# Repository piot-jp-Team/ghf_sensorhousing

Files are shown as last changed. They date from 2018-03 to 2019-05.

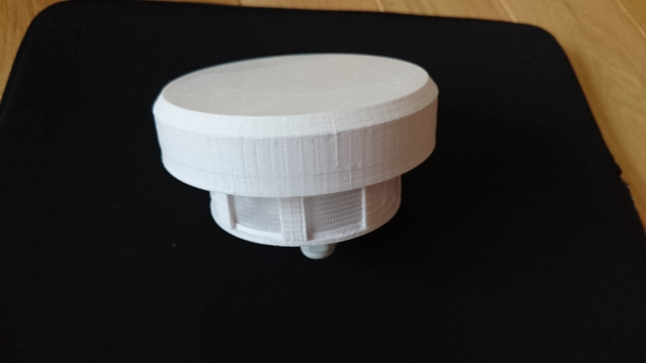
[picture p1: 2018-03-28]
DSC_0031.jpg

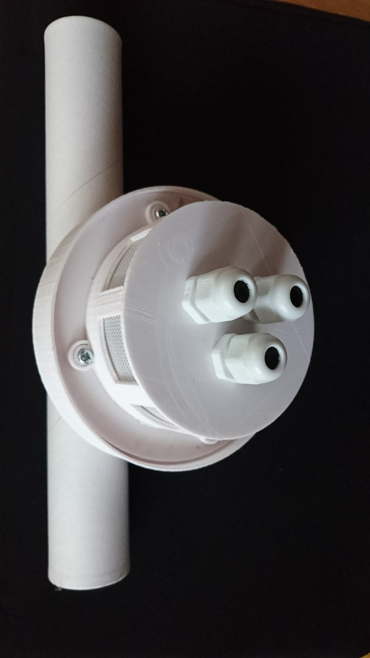
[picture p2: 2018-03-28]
DSC_0030.jpg

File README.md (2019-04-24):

# ghf_sensorhousing
## 農園センサーユニットハウジング
- arduino pro mini
- MH-Z19B 二酸化炭素センサ または　S-300G 二酸化炭素センサ
- AM2320 温湿度センサー
- リニア照度センサ
- 土壌水分センサ

## 仕組み
iot通信モジュールへRS485で取得データを送ります。  
sakura.io + arduino UNO  
sakura.ioから、laravel製のグラフで表示します。  
https://github.com/piot-jp-Team/ghf_webapp （日々更新中）  
シーケンス シーケンス図  

sakura.ioとの接続（Web Socket部分）は、https://github.com/piot-jp-Team/ghf_sakuraIO_wss_client  
今後はsigfox,lorawanも利用したいと思います。

## 使用するライブラリ   
(サーバ側)
- nginx, php7
- websocket クライアント　ratchetphp/Pawl
- phpフレームワーク laravel 5.6
- LaravelCharts
- mysql 5.7

(組み込み側)
- Arduino
- modbus/master slave
- S-300G or mhz19_uart
- Adafruit_Sensor
- Adafruit_AM2320
- sakura.io

## 開発ツール
- 筐体設計 OpenSCAD, FreeCAD
- PCB設計 Eagle6.6
- ファームウエア arduino IDE1.8.5
- エディタはATOM, PlantUML, Netbeans etc.

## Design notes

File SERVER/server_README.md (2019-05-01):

## サーバー側のソースコードは下記リポジトリです。  
Webアプリ  
https://github.com/piot-jp-Team/ghf_webapp 
  
sakura.io websocket　データ取得スクリプト  
https://github.com/piot-jp-Team/ghf_sakuraIO_wss_client

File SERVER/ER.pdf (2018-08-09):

エンティティ定義書 | 2018/8/9

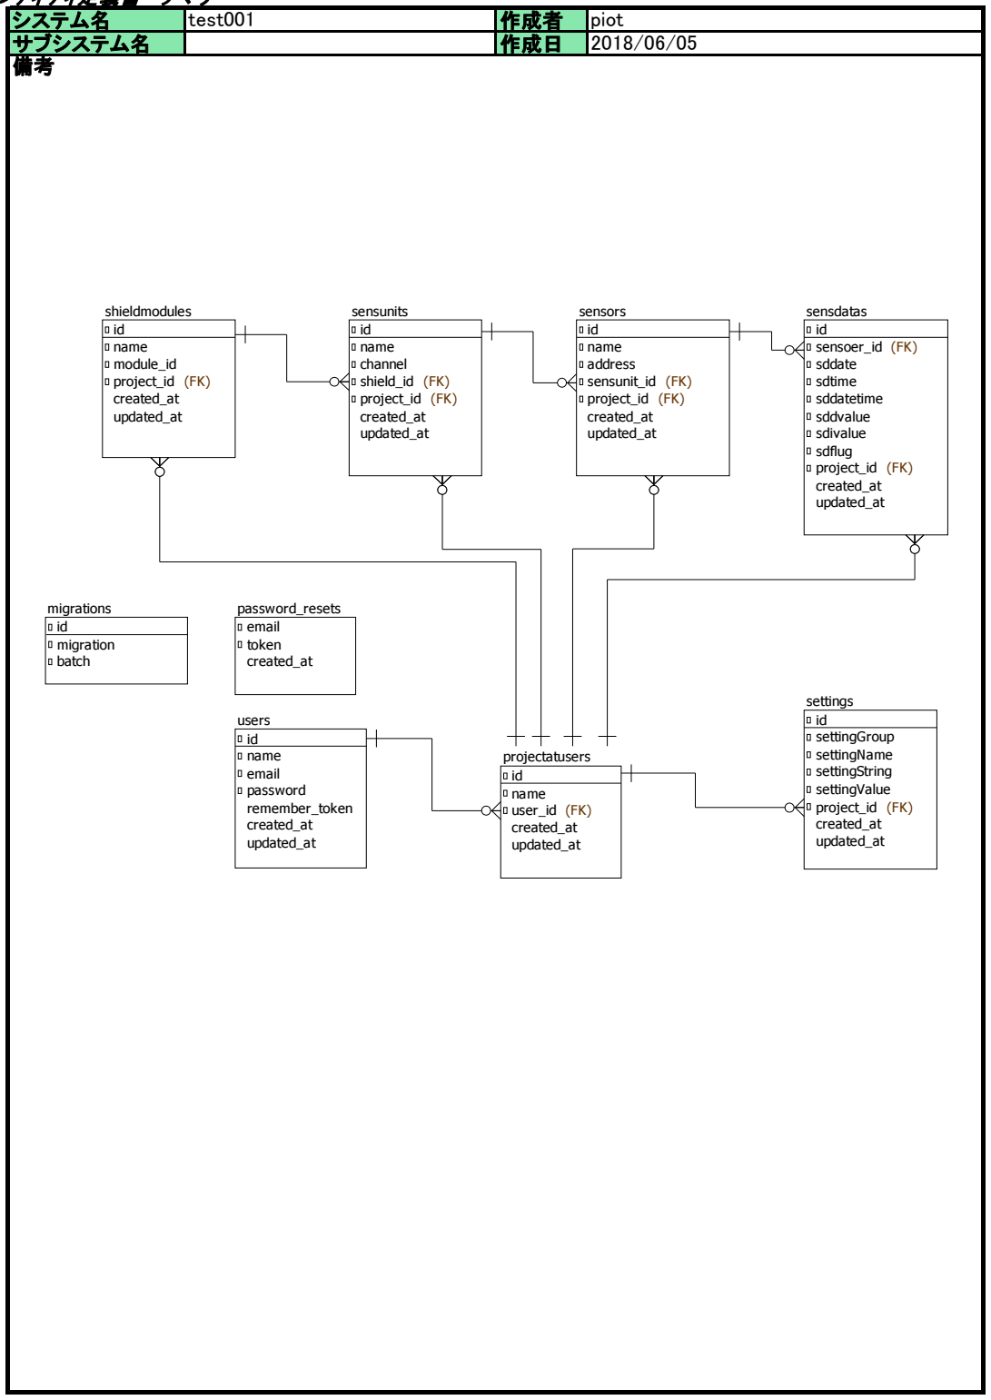
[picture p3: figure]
システム名; test001; 作成者; piot; サブシステム名; 作成日; migrations id migration batch; password_resets email token created_at; sensdatas id sensoer_id (FK) sddate sdtime sddatetime sddvalue sdivalue sdflug project_id (FK) created_at updated_at; sensors id name address sensunit_id (FK) project_id (FK) created_at updated_at; sensunits id name channel shield_id (FK) project_id (FK) created_at updated_at; settings id settingGroup settingName settingString settingValue project_id (FK) created_at updated_at; shieldmodules id name module_id project_id (FK) created_at updated_at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

## エンティティ定義書 サマリ

1/1

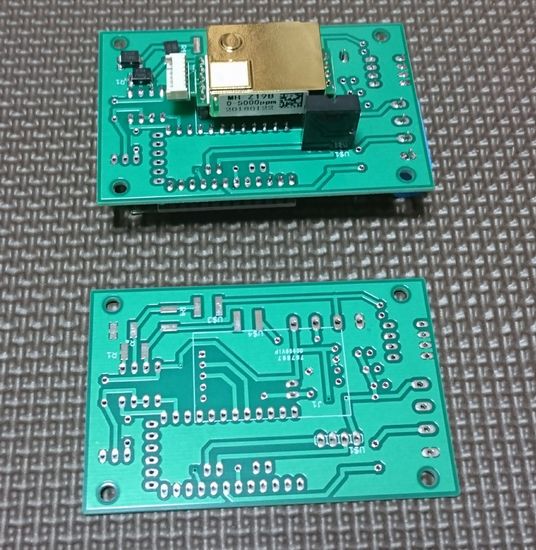
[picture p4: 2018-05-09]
PCB_bottomside.jpg

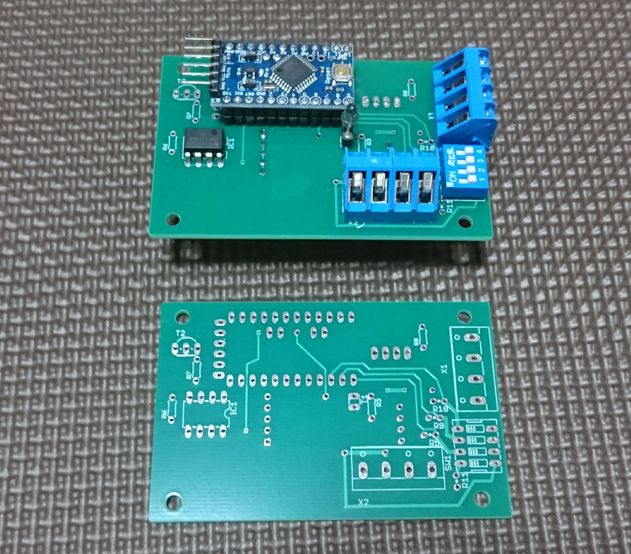
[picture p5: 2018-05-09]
PCB_topside.jpg

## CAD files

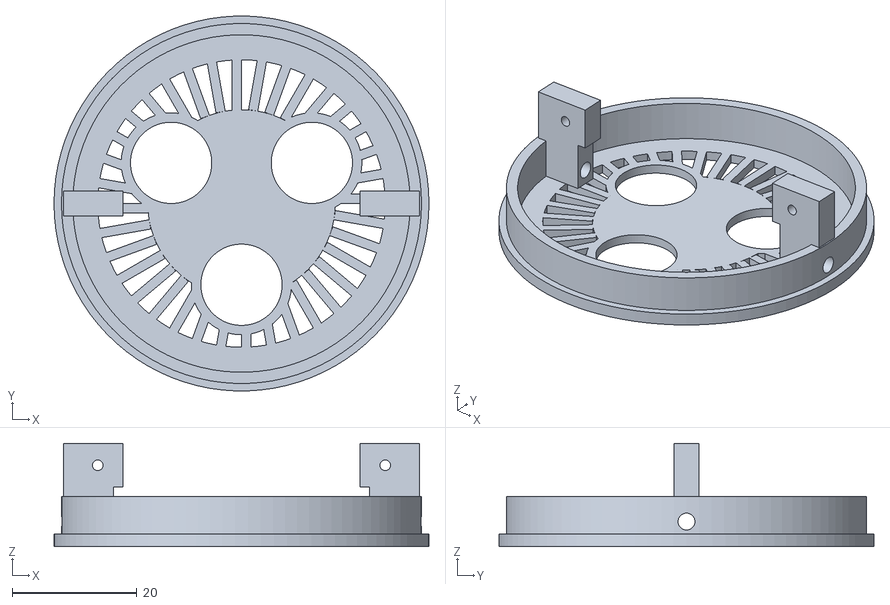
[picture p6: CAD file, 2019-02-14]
CAD/ghi_bottom.stl
60.0 x 60.0 x 16.5

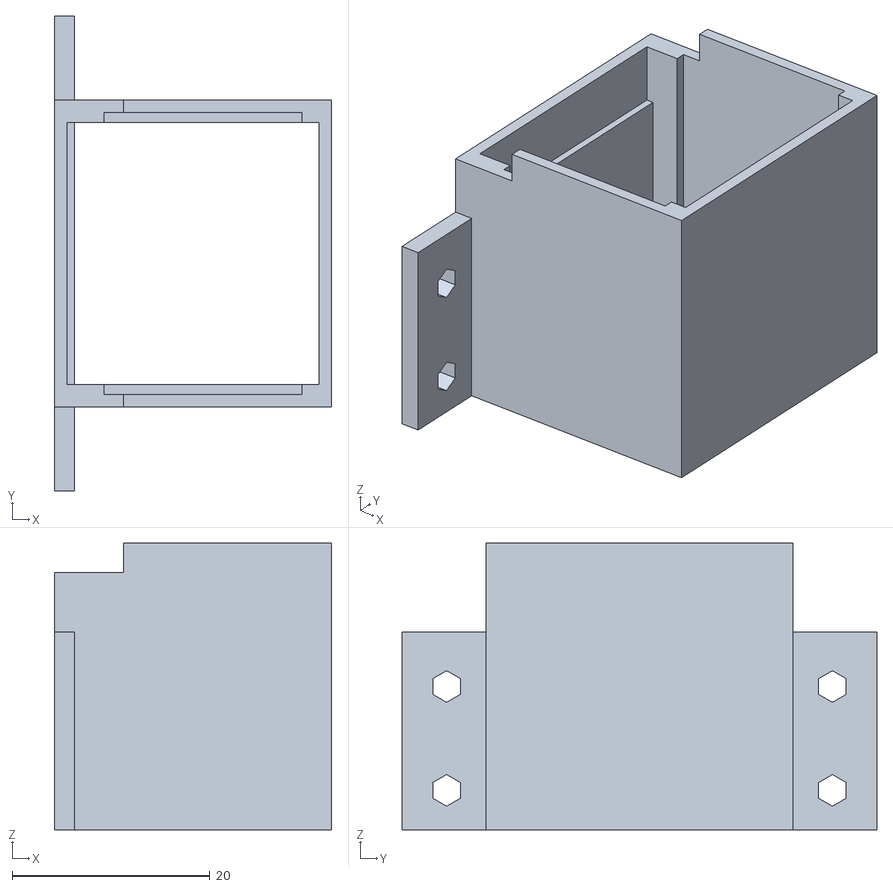
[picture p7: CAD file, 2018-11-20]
CAD/sakuraio_Holder/greenhouse_OutletHolderv2.stl
28.0 x 48.0 x 29.0

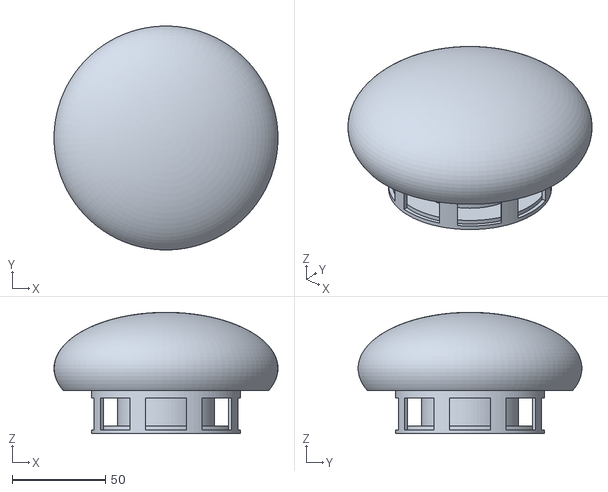
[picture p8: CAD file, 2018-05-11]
greenhouse_sensor_kinoko.stl
120.0 x 119.9 x 65.0

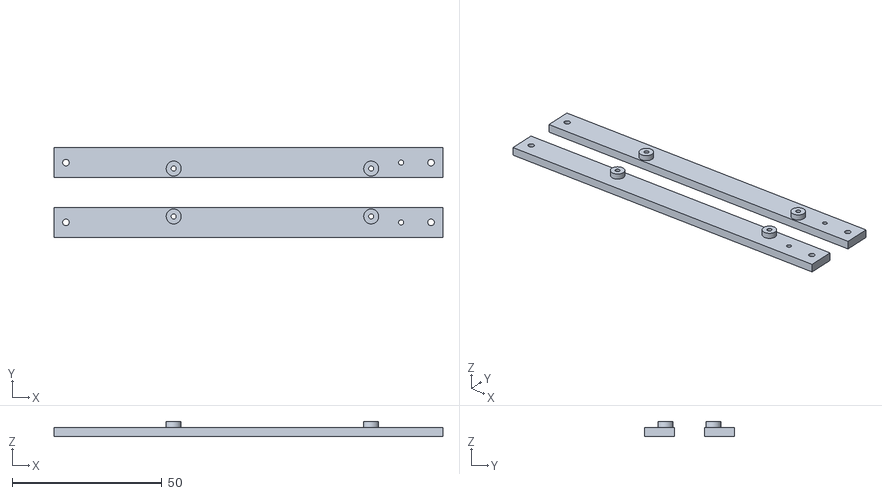
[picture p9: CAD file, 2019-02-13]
CAD/ghi_pcbstay.stl
130.0 x 30.0 x 5.00

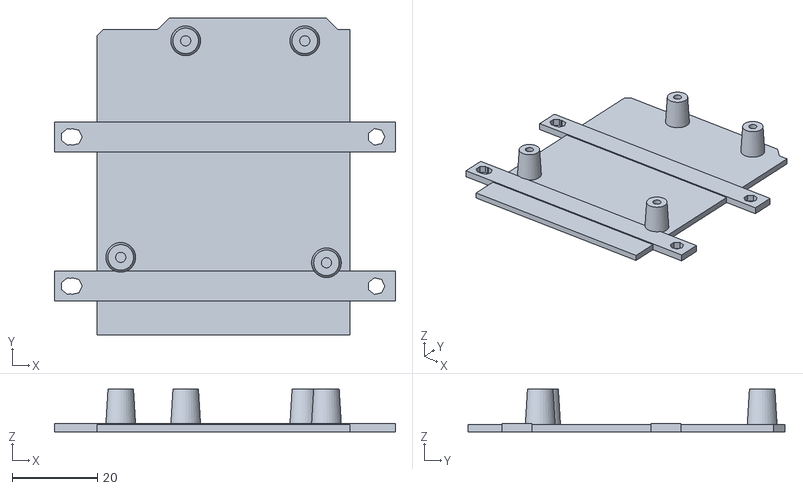
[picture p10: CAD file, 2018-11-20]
CAD/sakuraio_Holder/greenhouse_ArduinoBase.stl
80.0 x 74.4 x 10.0

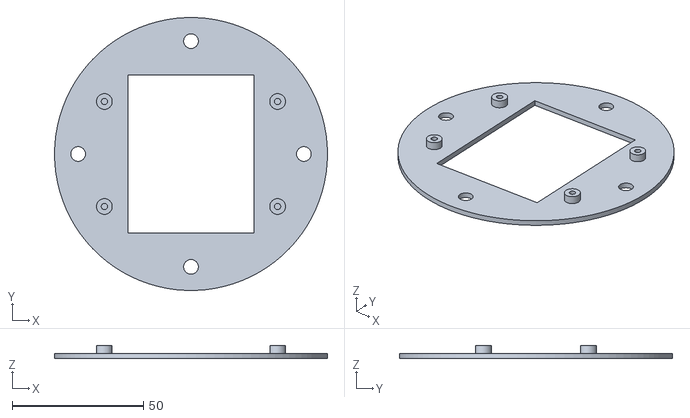
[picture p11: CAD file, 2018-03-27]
greenhouse_sens_pcbbase.stl
104.0 x 103.9 x 5.00

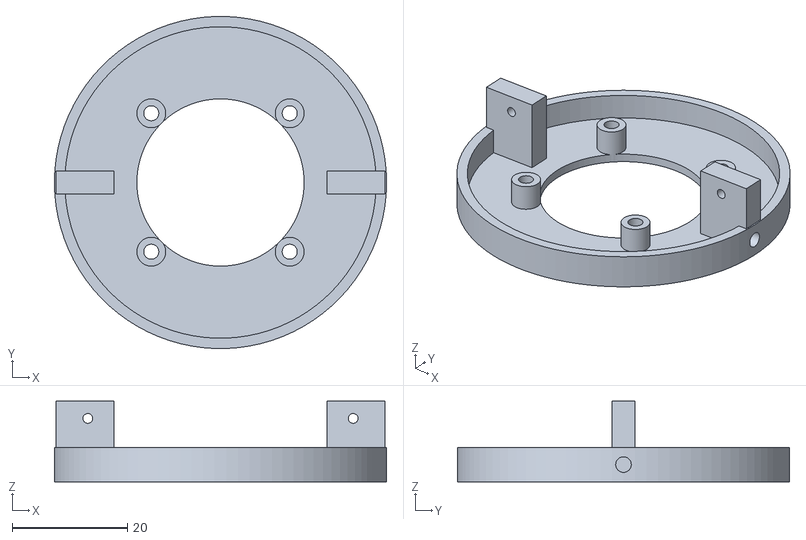
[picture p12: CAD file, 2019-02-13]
CAD/ghi_fanstay.stl
57.6 x 57.6 x 14.0

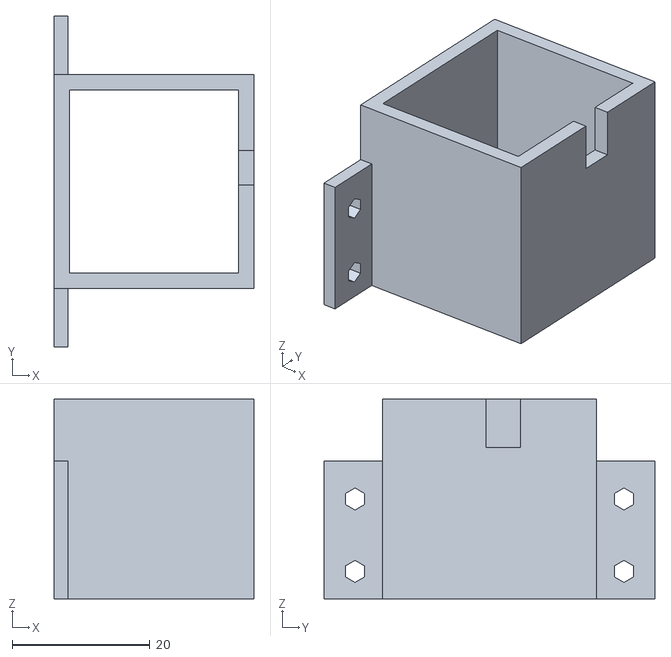
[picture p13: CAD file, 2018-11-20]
CAD/sakuraio_Holder/greenhouse_OutletHolder.stl
29.0 x 48.0 x 29.0

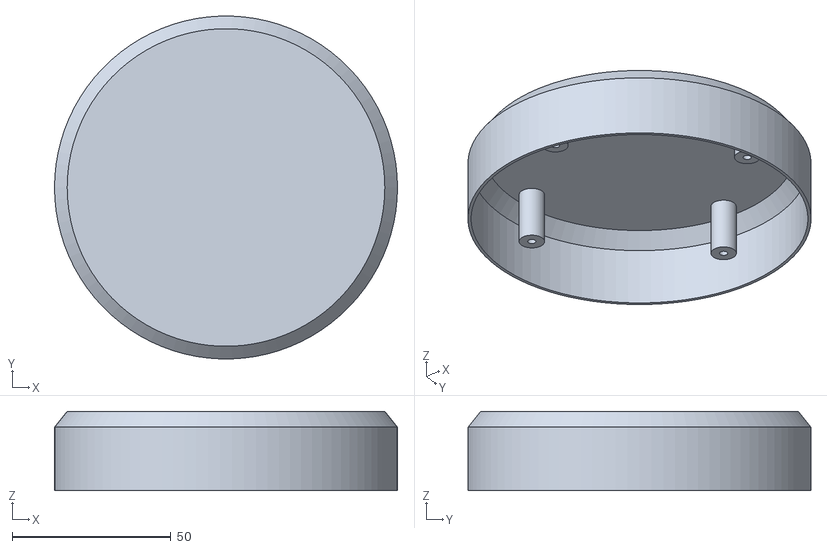
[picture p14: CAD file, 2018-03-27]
greenhouse_sens_topcover.stl
108.0 x 107.9 x 25.0

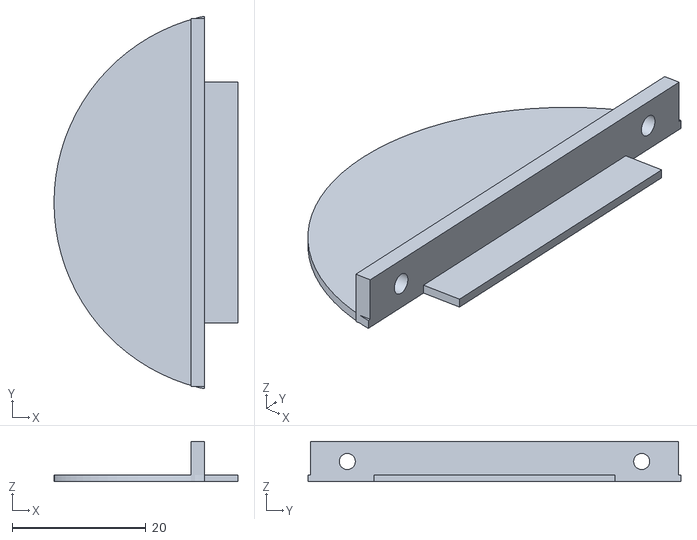
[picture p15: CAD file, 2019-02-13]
CAD/ghi_flowseparater.stl
27.5 x 55.7 x 6.00

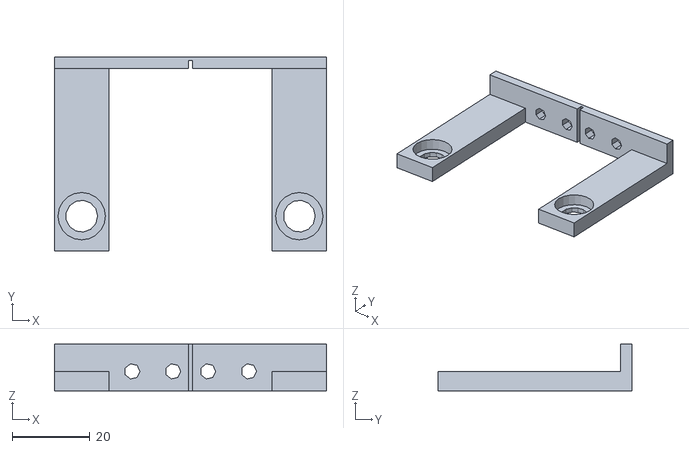
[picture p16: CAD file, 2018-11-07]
CAD/sakuraio_Holder/greenhouse_AntenaBracket.stl
70.0 x 50.0 x 12.0

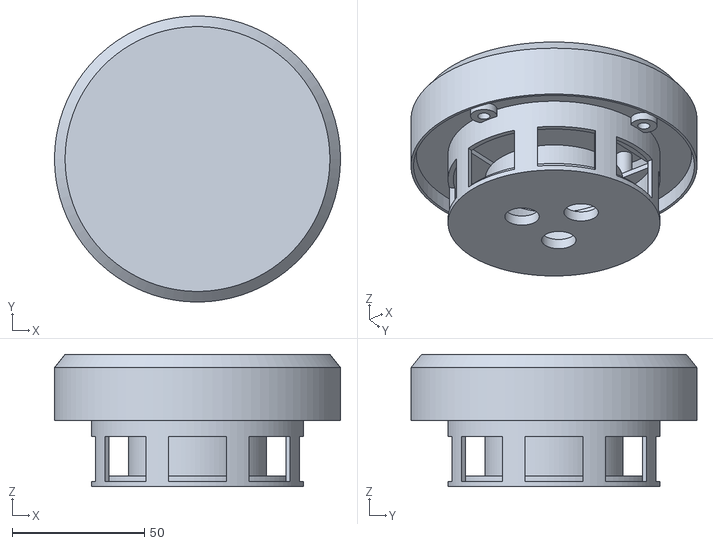
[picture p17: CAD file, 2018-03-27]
greenhouse_sensor.stl
108.0 x 107.9 x 50.0

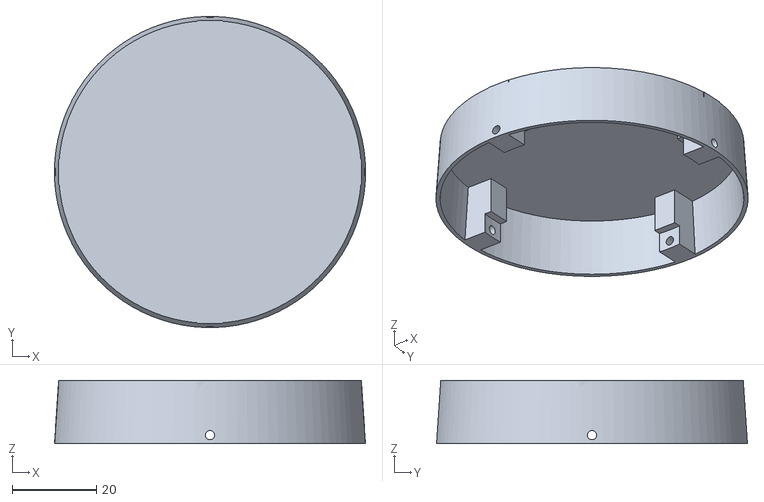
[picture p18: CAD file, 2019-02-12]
CAD/ghi_covertop.stl
74.0 x 74.0 x 15.0

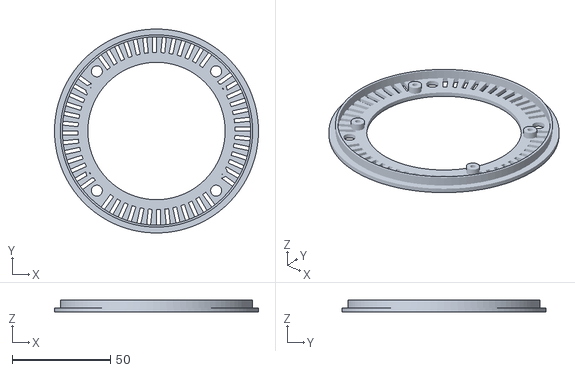
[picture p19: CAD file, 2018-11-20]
CAD/greenhouse_sens_kibanbasev2.stl
104.0 x 103.9 x 6.00

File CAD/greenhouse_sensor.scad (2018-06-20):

$fn = 90;

//under_shell
%union () {

  difference () {
 //outer  
    translate ([0,0,2]) {
        cylinder (r1 = 40, r2 = 40, h= 28);
    }    
    translate ([0,0,2]) {
      cylinder (r1 = 38, r2 = 38, h= 28);
    }

//slit
    translate ([-50,-11,2]) {
        cube ([100,22,17]); 
    }
    rotate ([0,0,45]) {
        translate ([-50,-11,2]) {
            cube ([100,22,17]); 
        }
    }
    rotate ([0,0,90]) {
        translate ([-50,-11,2]) {
            cube ([100,22,17]); 
        }
    }
    rotate ([0,0,135]) {
        translate ([-50,-11,2]) {
            cube ([100,22,17]); 
        }
    }
    
  }
  // neji_hole
  translate ([43,0,30-3]) {
      difference () {  cylinder (r1 = 5, r2 = 5, h= 3);
      cylinder (r1 = 2.3, r2 = 2.3, h= 3);}
  }
  rotate ([0,0,90]) {  translate ([43,0,30-3]) {
      difference () {  cylinder (r1 = 5, r2 = 5, h= 3);
      cylinder (r1 = 2.3, r2 = 2.3, h= 3);}
  }}
  rotate ([0,0,180]) {  translate ([43,0,30-3]) {
      difference () {  cylinder (r1 = 5, r2 = 5, h= 3);
      cylinder (r1 = 2.3, r2 = 2.3, h= 3);}
  }}
   rotate ([0,0,270]) { translate ([43,0,30-3]) {
       difference () { cylinder (r1 = 5, r2 = 5, h= 3);
       cylinder (r1 = 2.3, r2 = 2.3, h= 3);}
  }}
 }  

//bottom
%color("blue"){  
  %union () {
    difference () { 
          cylinder (r1 = 26, r2 = 26, h= 19);  
          cylinder (r1 = 25, r2 = 25, h= 19);
  
      }
      
      difference(){
          union(){
            cylinder (r1 = 38, r2 = 38, h= 4);
            cylinder (r1 = 40, r2 = 40, h= 2);
          }
        rotate(120)
            translate ([13,0,0]) 
                cylinder (r1 = 6.5, r2 = 6.5, h= 12);
        rotate(240)
            translate ([13,0,0]) 
                cylinder (r1 = 6.5, r2 = 6.5, h= 12);
        translate ([13,0,0]) 
            cylinder (r1 = 6.5, r2 = 6.5, h= 12);  
      }
  }
  }
//kiban
  rotate ([0,0,45]) {
  %translate ([-72/2,-48/2,35]) {
   difference () {   
    cube ([72,48,1.6]);
      translate ([3,3,0]){
          cylinder (r1 = 1.5, r2 = 1.5, h= 1.6); 
        }
        translate ([3,3+42,0]){
          cylinder (r1 = 1.5, r2 = 1.5, h= 1.6); 
        }
        translate ([3+66,3+42,0]){
          cylinder (r1 = 1.5, r2 = 1.5, h= 1.6); 
        }
        translate ([3+66,3,0]){
          cylinder (r1 = 1.5, r2 = 1.5, h= 1.6); 
        }
   }   
 }  
 }
 

  
 
 
  //kiban_base
%color("red")
%union(){
     translate ([0,0,30]) {
      difference(){
          cylinder (r1 =52, r2 = 52, h= 2);
          rotate ([0,0,45]) {translate ([-48/2,-60/2,0]){
            cube ([48,60,2]);
          }}
          rotate ([0,0,0]) {translate ([43,0,0]) {
            cylinder (r1 = 2.8, r2 = 2.8, h= 2);}
          }    
          rotate ([0,0,90]) {translate ([43,0,0]) {
            cylinder (r1 = 2.8, r2 = 2.8, h= 2);}
          }         
          rotate ([0,0,180]) {translate ([43,0,0]) {
            cylinder (r1 = 2.8, r2 = 2.8, h= 2);}
          }    
          rotate ([0,0,270]) {translate ([43,0,0]) {
            cylinder (r1 = 2.8, r2 = 2.8, h= 2);}
          }    
      }
      
rotate ([0,0,45]) {
      translate ([-72/2,-46/2,0]) {
        translate ([3,3,2]){
            difference(){
              cylinder (r1 = 3, r2 = 3, h= 3); 
              cylinder (r1 = 1.2, r2 = 1.2, h= 3); 
            }
        }
        translate ([3,3+40,2]){
            difference(){
              cylinder (r1 = 3, r2 = 3, h= 3); 
              cylinder (r1 = 1.2, r2 = 1.2, h= 3); 
            }
        }
        translate ([3+66,3+40,2]){
            difference(){
              cylinder (r1 = 3, r2 = 3, h= 3); 
              cylinder (r1 = 1.2, r2 = 1.2, h= 3); 
            }
        }
        translate ([3+66,3,2]){
            difference(){
              cylinder (r1 = 3, r2 = 3, h= 3); 
              cylinder (r1 = 1.2, r2 = 1.2, h= 3); 
            }
        }
      }
  }
    }
}

translate ([0,0,25]){
union(){
    rotate_extrude()
      polygon( points=[
[0,25],
[50,25],
[54,20],
[54,0],
[53,0],
[53,19],
[49,24],
[0,24]
] );
  // neji_boss
translate ([0,0,7]) {
  translate ([43,0,0]) {
      difference () {  cylinder (r1 = 4, r2 = 4, h= 18);
      cylinder (r1 = 1.3, r2 = 1.3, h= 18);}
      translate ([4,0,0])rotate ([0,0,-90])cube([1,7,14]);
  }
  rotate ([0,0,90]) {  translate ([43,0,0]) {
      difference () {  cylinder (r1 = 4, r2 = 4, h= 18);
      cylinder (r1 = 1.3, r2 = 1.3, h= 18);}
      translate ([4,0,0])rotate ([0,0,-90])cube([1,7,14]);
  }}
  rotate ([0,0,180]) {  translate ([43,0,0]) {
      difference () {  cylinder (r1 = 4, r2 = 4, h= 18);
      cylinder (r1 = 1.3, r2 = 1.3, h= 18);}
      translate ([4,0,0])rotate ([0,0,-90])cube([1,7,14]);
  }}
   rotate ([0,0,270]) { translate ([43,0,0]) {
       difference () { cylinder (r1 = 4, r2 = 4, h= 18);
       cylinder (r1 = 1.3, r2 = 1.3, h= 18);}
       translate ([4,0,0])rotate ([0,0,-90])cube([1,7,14]);
  }}
}
}
}  
//  translate ([-50,-100,0]) {
//    cube ([100,100,105]);
// }
//}


/*
%difference () {
  union () {
    cylinder (r1 = 40, r2 = 50, h= 75);
    translate ([40,0,40]) {
      rotate ([90,0,0]) {
        rotate_extrude () {
          translate ([30,0,0]) {
            circle (r = 5);
          }
        }
      }
    }
  }
  translate ([0,0,5]) {
    cylinder (r1 = 35, r2 = 45, h= 75-2.5);
  }
}

*/

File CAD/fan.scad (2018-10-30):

echo(version=version());

color("gray")

        linear_extrude(height = 10)
        difference(){
            square([40, 40], center = true);
            circle(18, center = true);
            translate([16.5, -16.5, 0])circle(2, center = true);
            translate([16.5, 16.5, 0])circle(2, center = true);
            translate([-16.5, 16.5, 0])circle(2, center = true);
            translate([-16.5, -16.5, 0])circle(2, center = true);
        }

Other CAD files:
CAD/greenhouse_sens_bottomv2.stl
CAD/greenhouse_sens_undershellv2.stl
CAD/greenhouse_sens_covertopv2.stl
CAD/undershell.step
CAD/greenhouse_sensor_covertopkinoko.scad
CAD/greenhouse_sensor_kinoko.scad
CAD/bottom.step
CAD/fan30.scad
CAD/ghf_caover_top_kinoko.scad
CAD/ghf_caover_top_kinoko_die.scad
CAD/ghf_caover_top_kinoko_die.stl
CAD/ghf_caover_top_kinoko_die_sekkou_mold.stl
CAD/ghi_bottom.scad
CAD/ghi_covertop.scad
CAD/ghi_fanstay.scad
CAD/ghi_flowseparater.scad
CAD/ghi_pcbstay.scad
CAD/greenhouse_radiationsheildv3.scad
CAD/greenhouse_radiationsheildv3.stl
CAD/greenhouse_radiationsheildv3b.scad
CAD/greenhouse_radiationsheildv3b.stl
CAD/greenhouse_radiationsheildv3t.scad
CAD/greenhouse_radiationsheildv3t.stl
CAD/greenhouse_sens_bottom.scad
CAD/greenhouse_sens_bottom.stl
CAD/greenhouse_sens_bottomv2.scad
CAD/greenhouse_sens_coverfly.scad
CAD/greenhouse_sens_covertop.scad
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

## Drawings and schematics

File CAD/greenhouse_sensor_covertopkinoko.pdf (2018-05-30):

# 楕円体 長径内寸118

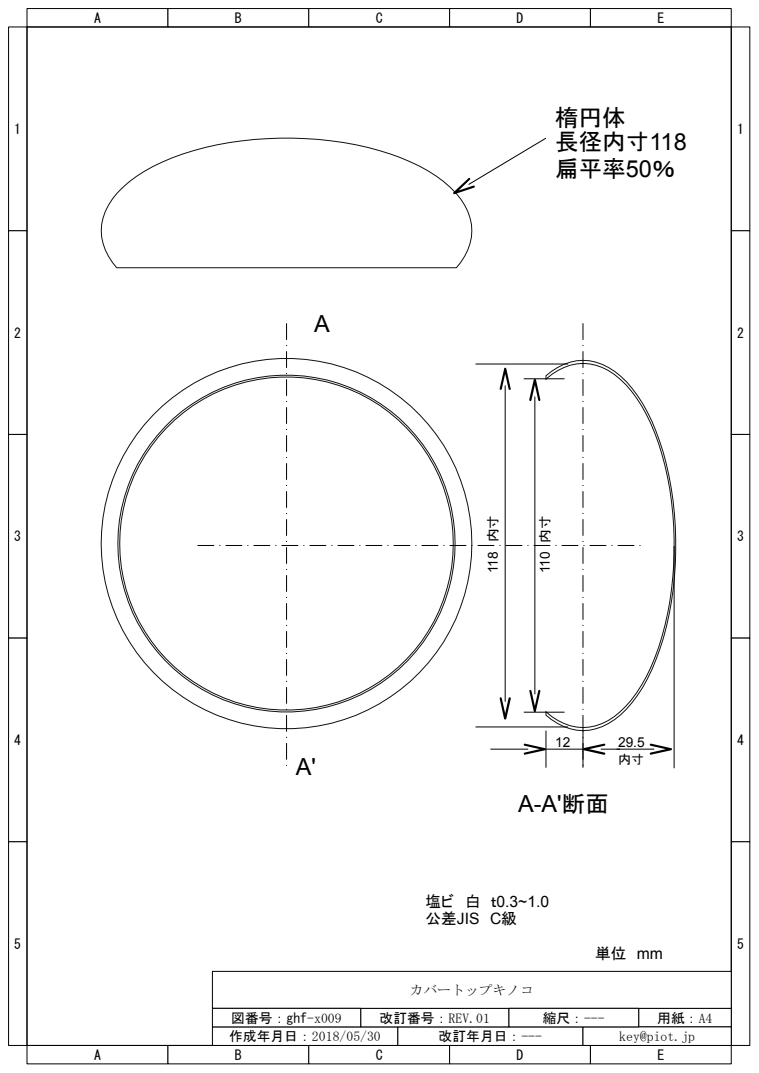
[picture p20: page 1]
カバートップキノコ; 扁平率50％; 塩ビ 白 ｔ0.3~1.0 公差JIS C級

図番号：ghf-x009 | 改訂番号：REV.01 | 縮尺：--- | 用紙：A4
作成年月日：2018/05/30 | 改訂年月日：--- | key@piot.jp

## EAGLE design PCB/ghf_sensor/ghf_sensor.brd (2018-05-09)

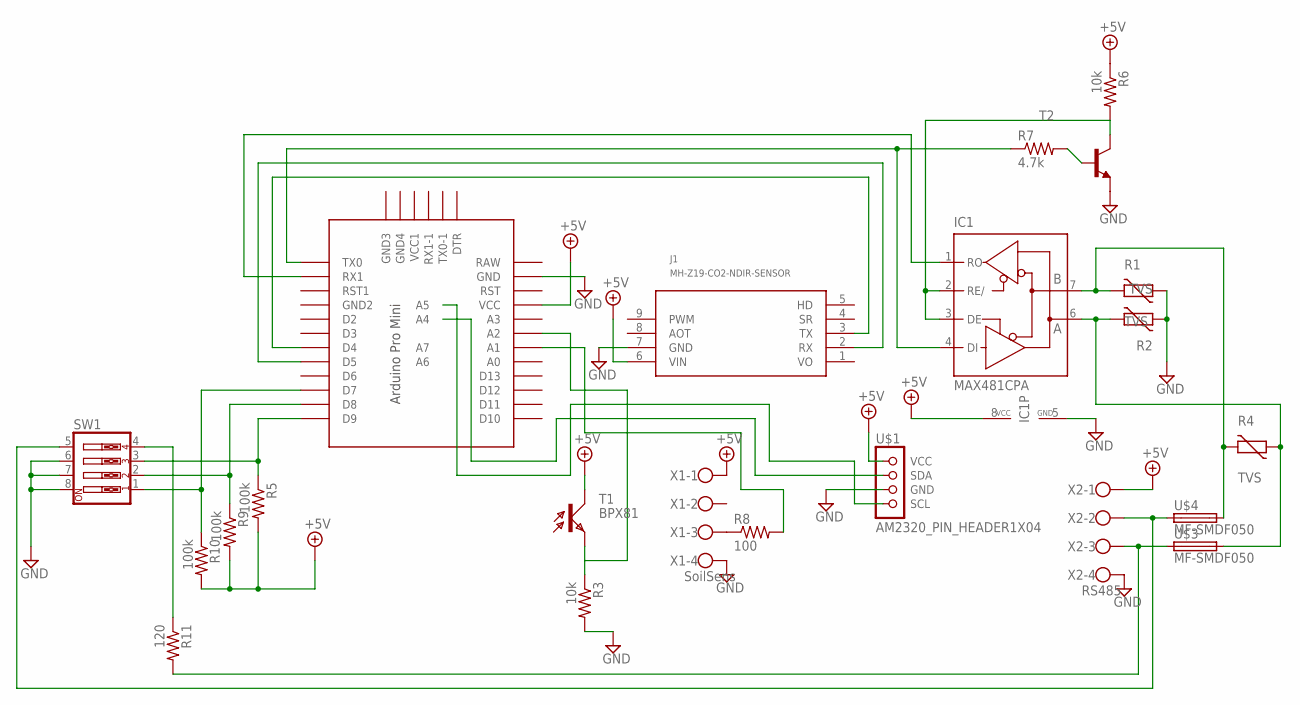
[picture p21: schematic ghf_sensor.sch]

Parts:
IC1: MAX481CPA; DIL08
J1: MH-Z19-CO2-NDIR-SENSOR; MH-Z19
R1, R2, R4: TVS; CT/CN1812
R3, R6: 10k; 0204/5
R5, R9, R10: 100k; 0204V
R7: 4.7k; 0204/5
R8: 100; 0204/5
R11: 120; 0204V
SW1: SW_DIP-4; EDG-04
T1: BPX81
T2: -NPN-TO92-ECB; TO92-ECB
U$1: AM2320_PIN_HEADER1X04; 1X04
U$2: PRO-MINI-2
U$3, U$4: MF-SMDF050
X1: SoilSens; W237-4
X2: RS485; W237-4

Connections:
+5V: IC1.8 (VCC), J1.6 (VIN), R5.2, R6.1, R9.2, R10.2, T1.C, U$1.1 (VCC), U$2.VCC, X1.1, X2.1
GND: IC1.5 (GND), J1.7 (GND), R1.1, R2.2, R3.2, SW1.6, SW1.7, SW1.8, T2.E, U$1.3 (GND), U$2.GND, X1.4, X2.4
unnamed: R3.1, T1.E, U$2.A2
unnamed: SW1.5, U$4.1, X2.2
unnamed: R11.2, U$3.1, X2.3
unnamed: J1.3 (TX), U$2.D4
unnamed: J1.2 (RX), U$2.D5
unnamed: R8.1, X1.3
unnamed: IC1.1 (RO), U$2.RX1
unnamed: U$1.2 (SDA), U$2.A4
unnamed: U$1.4 (SCL), U$2.A5
unnamed: R5.1, SW1.3, U$2.D9
unnamed: IC1.2 (RE/), IC1.3 (DE), R6.2, T2.C
unnamed: R7.2, T2.B
unnamed: IC1.4 (DI), R7.1, U$2.TX0
unnamed: R8.2, U$2.A1
unnamed: R9.1, SW1.2, U$2.D8
unnamed: R10.1, SW1.1, U$2.D7
unnamed: R11.1, SW1.4
unnamed: IC1.7 (B), R1.2, R4.2, U$4.2
unnamed: IC1.6 (A), R2.1, R4.1, U$3.2
VO: J1.1 (VO)

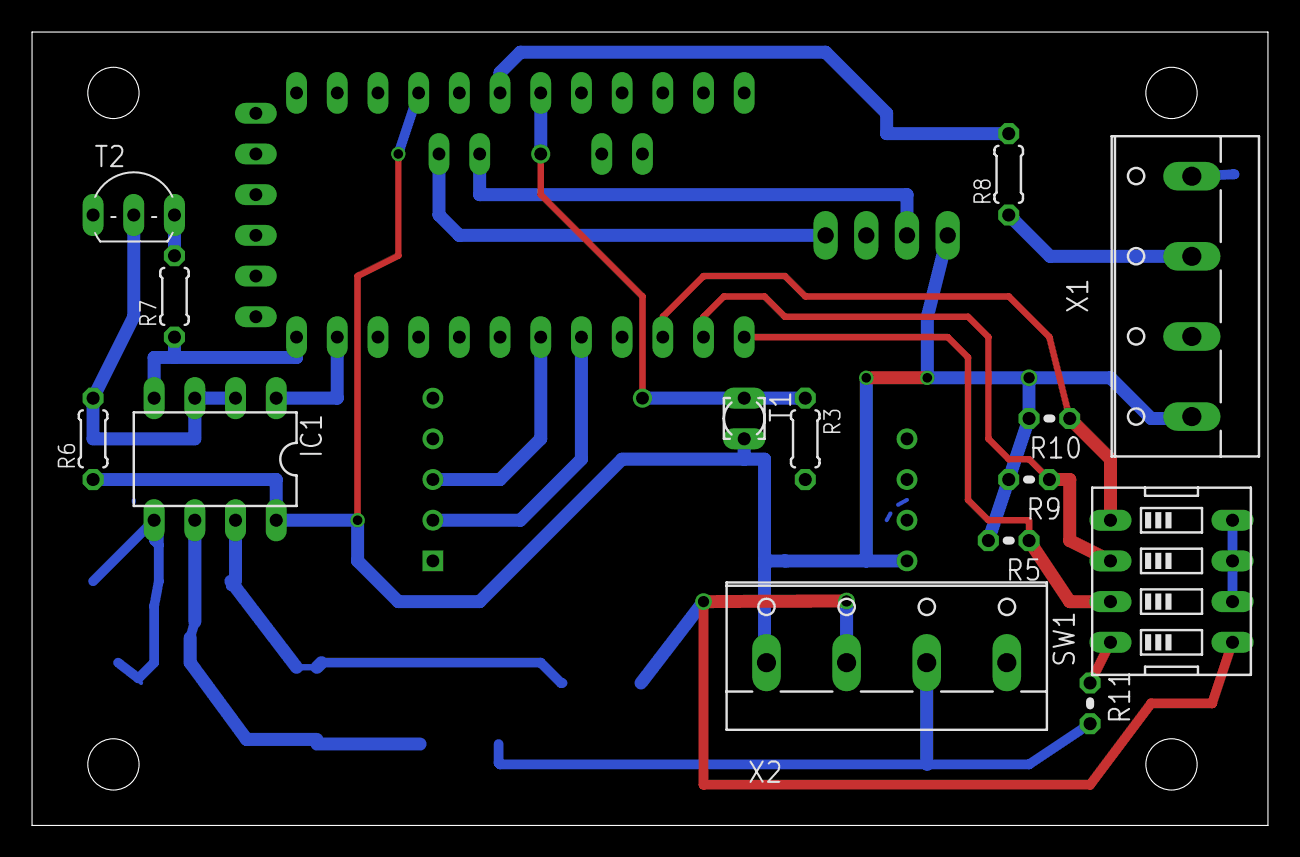
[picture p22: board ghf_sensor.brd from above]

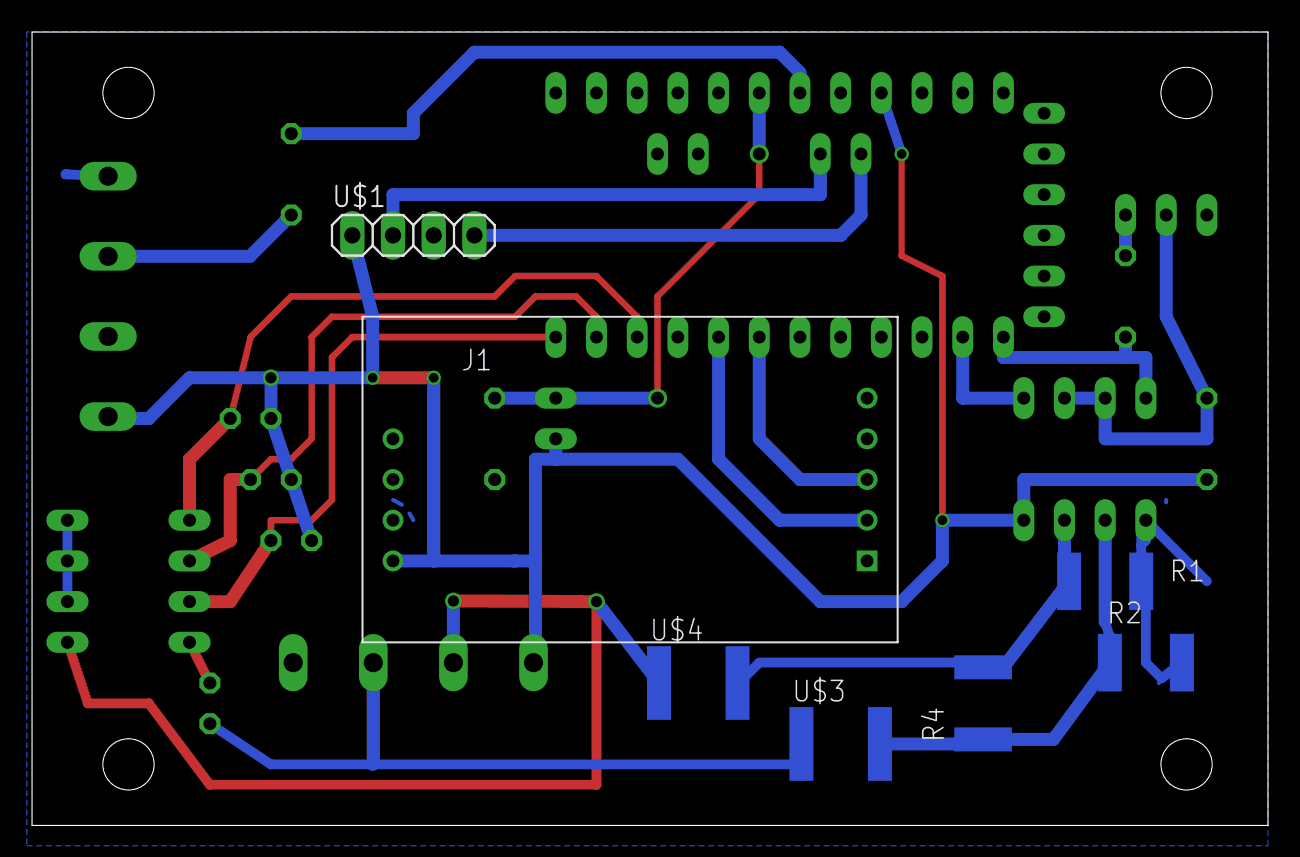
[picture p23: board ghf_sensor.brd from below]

Board: 2 copper layers, 77.1 x 49.5 mm, 22 parts (7 on the bottom side), 21 nets.

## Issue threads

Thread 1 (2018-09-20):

ELT S-300G co2 senser

yoshikichi, 2018-09-20:
co2 senser replace S-300

yoshikichi, 2018-10-02:
As for the output data of MH - Z19, as the relative humidity rises, the CO2 concentration also rises

yoshikichi, 2019-02-19:
自己レスです。結局メーカーに質問しました。
- 他にはELT D-400G(3V,5V,12V兼用) もあります。すこし高価ですが、安定しているそうです。

臨床実験したところ外気キャリブレしたら４００でなく１２１まで下がっていた現象について。
- 初期エージング不具合の可能性もあるので、S−３００もD−４００も設置後一度MCDLマニュアルキャリブレーションした方が良いということです。

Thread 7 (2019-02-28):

筐体を段ボールで作った場合

mikissa-s, 2019-02-28:
吸湿と紙粉が問題になるらしい。

https://gyazo.com/4c7ea9367302f37d73ffa30acd4c9e35

https://gyazo.com/456b0d932587756f9f59c513ad2bbe42

mikissa-s, 2019-03-01:
段ボールの含水率は通常８％。
環境に応じて、吸湿、排湿。
含水率１％UPで10%強度が落ちる。

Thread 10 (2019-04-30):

ER図の詳細について

mikissa-s, 2019-04-30:
sakura.io のドキュメントなのかコードと資料の乖離なのか、こちらもセンサーデータの例示をお願いしたいです。

yoshikichi, 2019-05-01:
すみません。サーバーER図はこちらよりwebappの関係なのでissueを移動します。
#https://github.com/piot-jp-Team/ghf_webapp/issues/11

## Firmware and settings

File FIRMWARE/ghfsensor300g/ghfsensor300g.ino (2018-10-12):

#include <Adafruit_Sensor.h>
#include <Adafruit_AM2320.h>
//#include <MHZ19_uart.h>
#include <ModbusRtu.h>
#include <SoftwareSerial.h>
const int rx_pin = 5;  //Serial rx pin no
const int tx_pin = 4; //Serial tx pin no
SoftwareSerial mySerial(rx_pin, tx_pin); // RX, TX
Adafruit_AM2320 am2320 = Adafruit_AM2320();
//MHZ19_uart mhz19;
int slaveID = 1;
Modbus slave(slaveID, 0, 0); // this is slave ID ,serial pin(0=default), tx_enable_pin(0=none)
int co2ppm = 0;

// data array for modbus network sharing
uint16_t au16data[6]; 
int8_t state = 0;
unsigned long tempus;

void setup() {
  // start communication
  slave.begin( 19200 );
  tempus = millis() + 100;

  mySerial.begin(38400); // ソフトウェアシリアルの初期化
  //mySerial.println("Hello, world?");
  
  am2320.begin();
  //mhz19.begin(rx_pin, tx_pin);
  //mhz19.setAutoCalibration(false);
  //while( mhz19.isWarming() ) {
  //  //Serial.print("MH-Z19 now warming up...  status:");Serial.println(mhz19.getStatus());
  //  delay(1000);
  //  break;  //ステータスがなかなか変わらないため、とりあえず進める
  //}

//自分のアドレス取得
//(D9 D8 D7)
bitWrite( slaveID, 0, !digitalRead( 7 ));
bitWrite( slaveID, 1, !digitalRead( 8 ));
bitWrite( slaveID, 2, !digitalRead( 9 ));
slaveID ++;
slave.setID(slaveID);
//Serial.print("slaveID: "); Serial.println(slaveID);

io_setup(); // I/O settings

}

void loop() {
  state = slave.poll( au16data, 6 );
  if(state!=0)digitalWrite(LED_BUILTIN, HIGH);
  //int temp2=am2320.readTemperature();
  //int hum=am2320.readHumidity();
  uint16_t temp2=am2320.readRegister16(AM2320_REG_TEMP_H); //signed x10(℃)
  uint16_t hum=am2320.readRegister16(AM2320_REG_HUM_H);    //x10(％)
  //int co2ppm = mhz19.getPPM();
  //int temp = mhz19.getTemperature();


  if (mySerial.available()){
    String co2 ;
    String co2num ;
    //co2 = mySerial.readStringUntil('\n');
    co2 = mySerial.readString();
    //Serial.print("rx: "); 
    //Serial.println(co2);
    co2num = co2.substring(0,6);
    co2ppm = co2num.toInt();
  }
  
  //Serial.print("co2: "); 
  //Serial.println(co2ppm);
  //char PPMX[2];
  //sprintf(PPMX,"%X", co2ppm);
  //Serial.print(PPMX);
  
  //Serial.print("temp: "); Serial.println(temp);
  //char TEMPX[2];
  //sprintf(TEMPX,"%X", temp);
  //Serial.print(TEMPX);
  //char HUMX[2];
  //sprintf(HUMX,"%X", hum);
  //Serial.print(HUMX);

  au16data[0]=temp2;
  au16data[1]=hum;
  au16data[2]=analogRead(1); //LUX
  au16data[3]=co2ppm;
  au16data[4]=analogRead(2); //Soil Hum
  au16data[5]=analogRead(0); //Soil PH (option)
/*  
Serial.print("slaveID: "); Serial.println(slaveID);
Serial.print("temp: "); Serial.println(temp);
Serial.print("co2: "); Serial.println(co2ppm);
Serial.print("temp2: "); Serial.println(temp2);
Serial.print("hum: "); Serial.println(hum);
Serial.print("au16data[0]"); Serial.println(au16data[0]);
Serial.print("au16data[1]"); Serial.println(au16data[1]);
Serial.print("au16data[2]"); Serial.println(au16data[2]);
Serial.print("au16data[3]"); Serial.println(au16data[3]);
Serial.print("au16data[4]"); Serial.println(au16data[4]);
Serial.print("au16data[5]"); Serial.println(au16data[5]);
*/
delay(100);
digitalWrite(LED_BUILTIN, LOW);

//リクエスト待機
//自分のアドレス一致したら応答
//ToDo

}

void io_setup() {
  // define i/o
  //pinMode(0, INPUT);
  //pinMode(1, INPUT);
  //pinMode(2, INPUT);
  //pinMode(7, INPUT);
  //pinMode(8, INPUT);
  //pinMode(9, INPUT);

pinMode(LED_BUILTIN, OUTPUT);
digitalWrite(LED_BUILTIN, LOW);

}

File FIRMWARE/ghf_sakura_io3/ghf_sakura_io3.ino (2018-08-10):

#include <SakuraIO.h>
#include <ModbusRtu.h>


// Sakura IO
SakuraIO_I2C sakuraio;

// data array for modbus network sharing
uint16_t au16data1[16];
uint16_t au16data2[16];
uint16_t au16data3[16];
uint16_t au16data4[16];
uint16_t au16data5[16];
uint16_t au16data6[16];
uint16_t au16data7[16];
uint16_t au16data8[16];
uint8_t u8state;
uint8_t countSendFlg;
Modbus master(0,0,0); // this is master and RS-232 or USB-FTDI
/**
 * This is an structe which contains a query to an slave device
 */
modbus_t telegram;
unsigned long u32wait;


void setup() {

  // オンラインになるまで待つ
  while ((sakuraio.getConnectionStatus() & 0x80) != 0x80) {
    delay(1000);
  }
  //ModBus設定
  master.begin( 19200 ); // baud-rate at 19200
  master.setTimeOut( 2000 ); // if there is no answer in 2000 ms, roll over
  u32wait = millis() + 1000;
  u8state = 0; 
  countSendFlg = 0;

}

void loop() {

  static uint32_t i;
  uint8_t j, result;
  uint16_t data[6];
  uint8_t ret;
  uint8_t requestFlg;
  
  i++;

  
  // 受信キューの状態を取得
  uint8_t rxAvailable;
  uint8_t rxQueued;
  uint8_t queued;
  sakuraio.getRxQueueLength(&rxAvailable, &rxQueued);

  // 受信キューにたまっているメッセージの数だけ繰り返す
  for (uint8_t i = 0; i < rxQueued; i++) {
    uint8_t channel;
    uint8_t type;
    uint8_t values[8];
    int64_t offset;

    // キューからのメッセージを取り出しに成功したら以下を実行
    uint8_t ret = sakuraio.dequeueRx(&channel, &type, values,
                                     &offset);
    if (ret == CMD_ERROR_NONE) {
/*
      Serial.print("channel: ");
      Serial.println(channel);
      Serial.print("type: ");
      Serial.println((char)type);
      Serial.print("value: ");
*/
      //0x03 - Read Holding Registers (channel:"1", type:i ,value:3)
      if (channel == 1 && values[0] == 3) {
            //ToDo  Tx Queue
            requestFlg = 1;
      }
    } else {
      //sakuraio.dequeueRx ERROR
      delay(5000);
    }
  }

  switch( u8state ) {
  case 0: 
    if (millis() > u32wait) u8state++; // wait state
    break;
  case 1: 
    telegram.u8id = 1; // slave address
    telegram.u8fct = 3; // function code (this one is registers read)
    telegram.u16RegAdd = 0; // start address in slave
    telegram.u16CoilsNo = 6; // number of elements (coils or registers) to read
    telegram.au16reg = au16data1; // pointer to a memory array in the Arduino

    master.query( telegram ); // send query (only once)
    u8state++;
    break;
  case 2:
    master.poll(); // check incoming messages
    if (master.getState() == COM_IDLE) {
      u8state = 0;
      u32wait = millis() + 2000; 
      //if(countSendFlg >= 20){
      if(countSendFlg >= 80){
        sakuraio.clearTx();
        sakuraio.enqueueTx(0,(int32_t)au16data1[0]);
        sakuraio.enqueueTx(1,(int32_t)au16data1[1]);
        sakuraio.enqueueTx(2,(int32_t)au16data1[2]);
        sakuraio.enqueueTx(3,(int32_t)au16data1[3]);
        sakuraio.enqueueTx(4,(int32_t)au16data1[4]);
        sakuraio.enqueueTx(5,(int32_t)au16data1[5]);
        sakuraio.send();
        countSendFlg = 0;
      }
      countSendFlg++;
    }
    break;
  }

/*
  if(queued >= 7){
    ret = sakuraio.clearTx();
    //Serial.print("Clear ");
    //Serial.println(ret);
  }else if(queued >= 1){ */
  /*
    if(requestFlg == 1){
      sakuraio.clearTx();
      sakuraio.enqueueTx(0,(uint32_t)au16data1[0]);
      sakuraio.enqueueTx(1,(uint32_t)au16data1[1]);
      sakuraio.enqueueTx(2,(uint32_t)au16data1[2]);
      sakuraio.enqueueTx(3,(uint32_t)au16data1[3]);
      sakuraio.enqueueTx(4,(uint32_t)au16data1[4]);
      sakuraio.enqueueTx(5,(uint32_t)au16data1[5]);
      sakuraio.send();
      //Serial.print("Send ");
      //Serial.println(ret);
      requestFlg = 0;
    }
 */   
/* } */
/*
    if(countSendFlg >= 20){
      sakuraio.clearTx();
      sakuraio.enqueueTx(0,(int32_t)au16data1[11]);
      sakuraio.enqueueTx(1,(int32_t)au16data1[12]);
      sakuraio.enqueueTx(2,(int32_t)au16data1[13]);
      sakuraio.enqueueTx(3,(int32_t)au16data1[14]);
      sakuraio.enqueueTx(4,(int32_t)au16data1[15]);
      sakuraio.enqueueTx(5,(int32_t)au16data1[16]);
      sakuraio.send();
      //Serial.print("Send ");
      //Serial.println(ret);
      countSendFlg = 0;
    }
    countSendFlg++;
*/
  delay(1000);
}

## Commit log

2018-03-27 add parts stl
    [greenhouse_sens_bottom.stl, greenhouse_sens_pcbbase.stl, greenhouse_sens_topcover.stl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]
2018-03-28 3D printed mock
2018-03-28 PCB sensor borad
    [ghf_sensor.brd, ghf_sensor.sch]
2018-03-29 PCB modified
    [ghf_sensor.brd, ghf_sensor.sch]
2018-05-09 add cad data, modify PCB board and schematic
    [ghf_sensor.GBL, ghf_sensor.GBO, ghf_sensor.GBP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]
2018-05-11 add kinoko top cover
    [greenhouse_sensor_kinoko.scad, greenhouse_sensor_kinoko.stl]
2018-05-11 mv stl
    [greenhouse_sensor_kinoko.scad]
2018-05-11 konoko cover modified
    [greenhouse_sensor_kinoko.scad]
2018-05-17 きのこカバー
    [greenhouse_sensor_covertopkinoko.scad, greenhouse_sensor_covertopkinoko.stl]
2018-05-21 add vacuum forming die
    [ghf_caover_top_kinoko.scad]
2018-05-21 separate forming die
    [ghf_caover_top_kinoko_die.stl]
2018-05-29 Add cad covertopkinoko file (iges and FreeCad)
    [covertopkinoko.FCStd, covertopkinoko.iges]
2018-05-29 old iges files remove
    [covertopkinoko.FCStd, covertopkinoko.iges]
2018-05-30 きのこカバー２Ｄ図面
2018-06-02 ad file ghf_caover_top_kinoko_die.scad
    [ghf_caover_top_kinoko_die.scad]
2018-06-02 ad file ghf_caover_top_kinoko_die_sekkou_mold.stl
    [ghf_caover_top_kinoko_die_sekkou_mold.stl]
2018-06-20 sakura.io arduino holder and antena bracket
    [arduino.scad, greenhouse_AntenaBracket.scad, greenhouse_AntenaBracket.stl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]
2018-06-20 aad rib for screw boss
    [greenhouse_sensor.scad]
2018-10-11 CAD housing update
    [greenhouse_sens_bottom.scad, greenhouse_sens_bottom.stl, greenhouse_sens_covertop.scad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]
2018-10-12 sensor firmware s-300g add
2018-10-16 CADD rediation shield add
    [greenhouse_radiationsheildv3.scad, greenhouse_radiationsheildv3.stl, greenhouse_radiationsheildv3b.scad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]
2018-10-30 CAD Modified
    [fan.scad, greenhouse_sens_coverfly.scad, greenhouse_sens_v2.scad]
2018-11-19 CAD undercshell modified
    [greenhouse_sens_undershellv2.scad, greenhouse_sens_undershellv2.stl]
2019-02-12 New version ghi_ add
    [fan30.scad, ghi_bottom.scad, ghi_bottom.stl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]
2019-02-13 dimension modified
    [ghi_fanstay.scad, ghi_fanstay.stl, ghi_flowseparater.scad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]
2019-02-14 bottom screw mounting outer demension modified
    [ghi_bottom.scad, ghi_bottom.stl]
